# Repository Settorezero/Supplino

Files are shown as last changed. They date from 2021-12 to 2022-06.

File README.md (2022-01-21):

# Supplino

Supplino is a _Quick & Dirty_ PSU (_Power Supply Unit_) made with some widely available breakout boards, an Arduino Nano (or an Arduino Nano Every) and a graphical LCD.

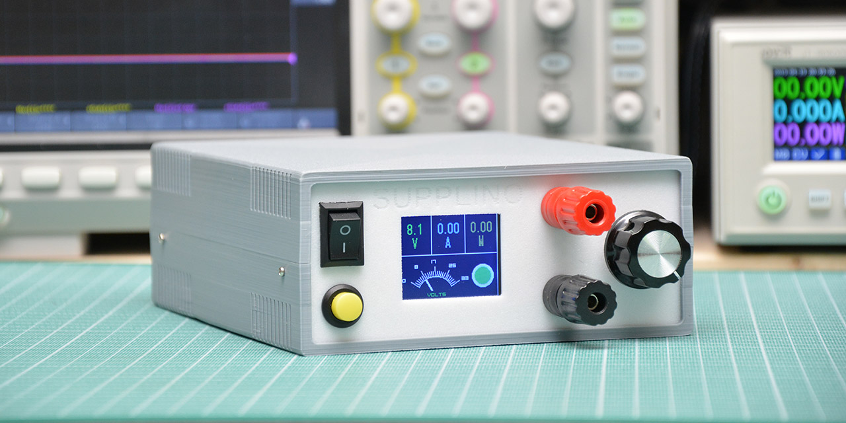
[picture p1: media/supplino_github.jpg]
Supplino
  

Supplino is the circuit between a costant current power source you choose and your target load. This is a flowchart showing how Supplino is made:

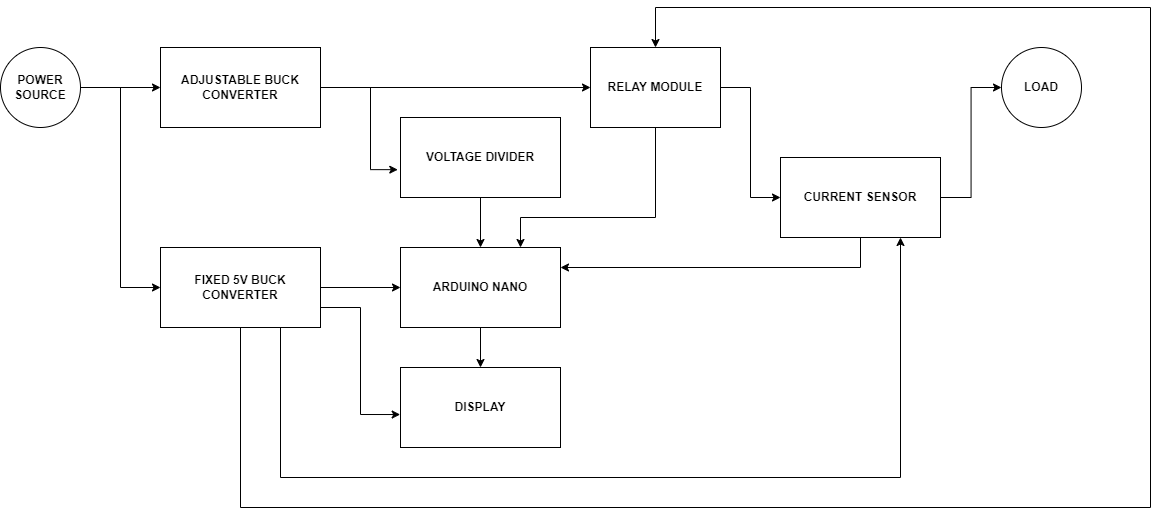
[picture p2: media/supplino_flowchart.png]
Supplino Flowchart


Power output is given by a DC/DC buck converter based on the XL4016E1 IC. Regarding the power source, we prefer feeding it through an external 20÷30V brick PSU such as the ones used for laptops or old printers: this solution is safe, but you can choose to use a larger enclosure and then include internally your own transformer+diode bridge+capacitors. Also the voltage regulation module can be changed.

Arduino does not manage the buck converter module but only measures output voltage and current (through a current sensor) and then shows those values on a display. Power value is showed too. An additional analog gauge can be configured for showing voltage, current or power value giving some retro style to the graphics.

Power output is feed through a relay, so Arduino detaches the output power sensing an external pushbutton or on alarm events (short circuit/under voltage, over-load, over-voltage).

There is a secondary DC/DC buck converter module set to 5V for powering the logics, taking input from the same input of the adjustable module.

We choosed this configuration since is cheap, simple and fully adaptable to other kinds of voltage converter designs, so the final user can choose whatever he want, also based on old-style linear voltage regulators such as the LM317 or LM338K.

We named it Supplino since we like a lot an italian snack typical of the roman cuisine, called [Supplì](https://en.wikipedia.org/wiki/Suppl%C3%AC) and because is the contraption of "Supply" and "Arduino".

### About the XH-M401 module

The XH-M401 module is based around the XL4016E1 buck converter IC. It can accept as input 4÷40V and gives an output 1.25÷36V. Manufacturer of those boards states a maximum output current of 5A that can be increased up to 8A by adding a fan, anyway we never used it for currents above 2A. This module has a switch-potentiometer for turning on/off the module and adjust the output voltage. The output current is fixed to the maximum allowable by the buck converter.

For using this module with enclosure we've designed and provided here you must remove the switch-potentiometer:

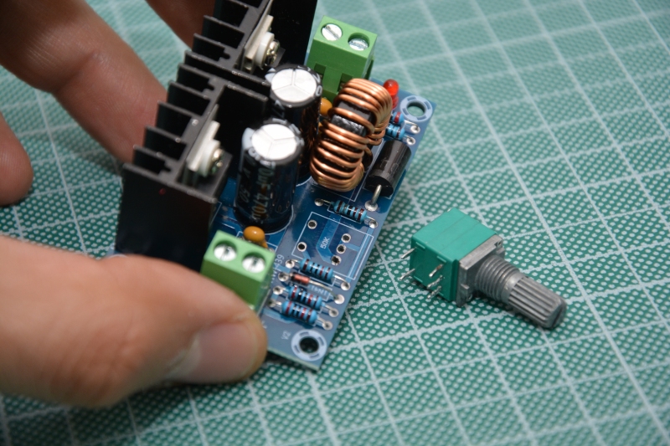
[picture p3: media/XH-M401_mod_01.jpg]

 
and then connect to the pads a 50K Multi-turn Potentiometer (better if used a JST-XH 3 pin connector) and then close with a piece of wire the switch pads (you'll turn on/off the module with a panel switch):

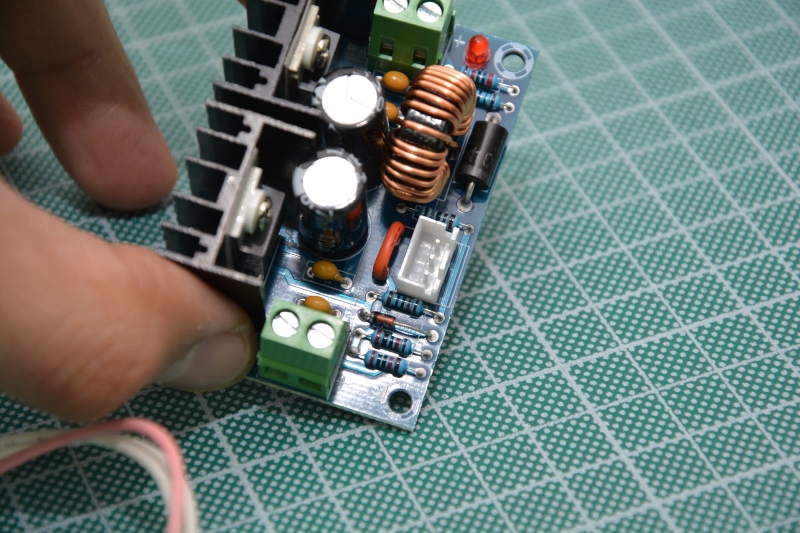
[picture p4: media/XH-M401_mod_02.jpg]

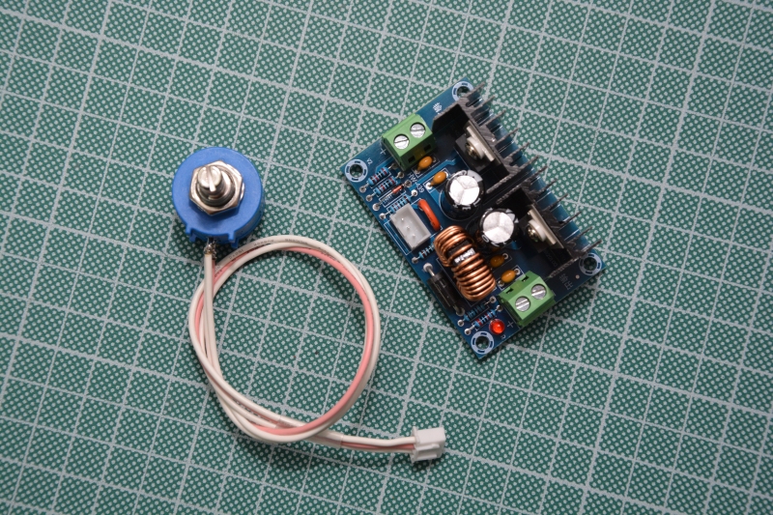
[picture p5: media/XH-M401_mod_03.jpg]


Is not adviced using a normal/single-turn potentiometer since you'll not be able to adjust the voltage in a stable manner.

- More info about the XH-M401 module: [(link)](https://www.instagram.com/p/CVqZ94OLAFN/)
- How to remove the switch-potentiometer and attach a new multi-turn one: [(link)](https://www.instagram.com/p/CWJXj0tLJGL/)

A new model of this module exists having also the possibility to regulate (_limit_) the output current [(link)](https://amzn.to/32PbnVB). This module has the same circuital design of the XH-M401 but buck converter and double diode are mounted on two separates heatsinks and it hasn't the switch-potentiometer but 2 multi-turn trimmers for adjusting voltage and current. In this case you'd remove both the trimmers, changing them with multiturn potentiometer (for voltage) and a normal single-turn linear potentiometer (for current - or a multi-turn if you want). In this case the provided enclosures will not usable anymore, so you must do your own design or choose a commercial one.

### First steps

1) Feed power in the buck converter module (LM2596s) used for giving 5V to logics. Turn the trimmer until you read 5.00V with a multimeter on the output pads. Usually a lot of turns are needed: if nothing happens after a lot of turns, try to turn in the opposite way.

2) Modify the buck converter module (XH-M401) for having the external multi-turn potentiomer and close the switch pads as explained above.

3) After you mounted all, first than attach the Arduino, check with a multimeter all the connections. Follow the schematic.

### About Arduino Nano / Every

You can use an Arduino Nano or an Arduino Nano Every. If you want to use an original Arduino board (adviced), better use the Every since is more capable (=more code) and costs less.

**Arduino Nano** : Select the board from `Tools > Board > Arduino AVR Boards > Arduino Nano`.
Most of non-original Arduino Nano boards requires to be configured in Arduino IDE for using the old bootloader: `Tools > Processor > ATMega328P (old bootloader)`. 

**Arduino Nano Every**: Pinout of this board is compatible 1:1 with the Nano. Select the board from `Tools > Board > Arduino megaAVR Boards > Arduino Nano Every`. For using the code unchanged select `Tools > Registers Emulation > ATMEGA328`

### Enclosure

We've designed 2 different enclosures. They're both based on the [Ultimate Box Maker](https://www.thingiverse.com/thing:1264391) by "HeartMan" on Thingiverse and are made for modules we used and listed in the "required parts" paragraph.

You can download and customize the original enclosure project from Thingiverse if you want to make your own enclosure. See [/cad/stl folder](/cad/stl) for further informations on provided STLs to be 3Dprinted.  
  
In the part list are listed 2 protoboards to be used with the Enclosure Variant1 : The 50x70 one will house connectors, LM2596 buck converter, Arduino Nano and components. The 30x70 protoboard will house the level shifter and the display.  

### Schematic

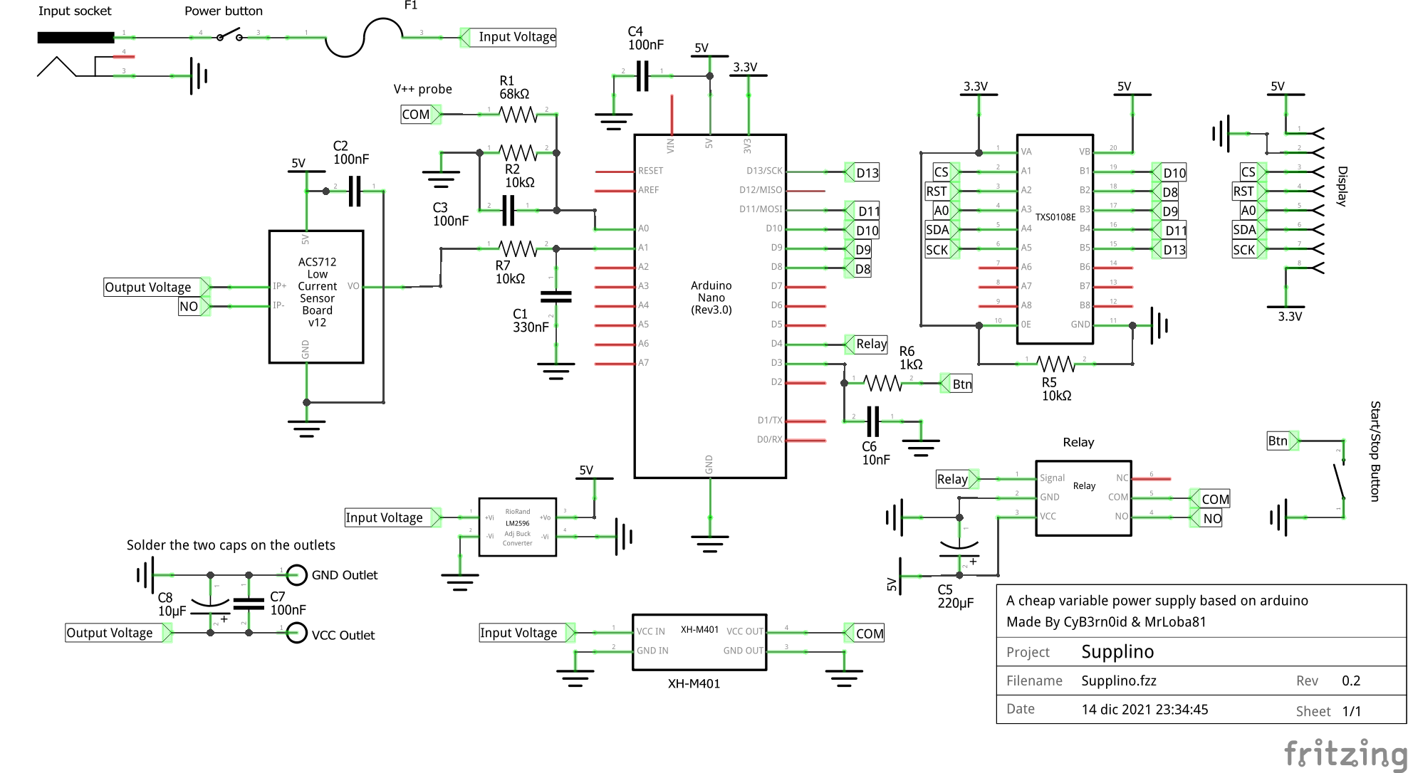
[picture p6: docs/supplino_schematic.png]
schematic


Please note : the resistor/capacitor on the pushbutton is strongly required for filtering noise that leads relay to attach/detach without reason.
 
### Required Parts

Following links contains an affiliation code for Italian Users so we can earn money if you buy something from following links (only valid for Amazon.it)

Internal parts:
- [1.8" 128x160 Display (ST7735)](https://amzn.to/3pBmids)
- [8bit Level Shifter - TXS0108E](https://amzn.to/3DoPg4V)
- [Current sensor 20A - ACS712](https://amzn.to/3osdSWe)
- [DC/DC Buck converter - LM2596s](https://amzn.to/3Ghmcyd)
- [DC/DC Buck converter XH-M401 - XL4016E1](https://amzn.to/3doaTaZ)
- [Relay Module](https://amzn.to/31yBUpw)
- [**Original** Arduino Nano Every](https://amzn.to/3qYmN1V) OR [**non original** Arduino Nano (classic)](https://amzn.to/3rADJxe) 
- [Protoboard 50x70 (link to protoboard kit)](https://amzn.to/34U1kQ4)
- [Protoboard 30x70 (link to protoboard kit)](https://amzn.to/34U1kQ4)

External/Panel mount parts:
- [Pushbutton](https://amzn.to/31wBQ9O)
- [Multi-turn 50K potentiometer](https://amzn.to/3ps1PHH)(choose 50K from the list)
- [Toggle Switch](https://amzn.to/3lFTNtJ)
- [Banana socket](https://amzn.to/3opLQuq)
- [Panel Barrel jack socket 5.5x2.1](https://amzn.to/3IrCOW2)
- Optional: [Panel USB-B to MINI-USB connector](https://amzn.to/3AdUpwO)(valid only if your board has MINI instead of MICRO USB)
- Panel Fuse-Holder + fuse based on your needs

Other parts
- [M3 Brass inserts](https://amzn.to/3EF1RlO)
- Adviced: [Crimping tool kit with Dupont and JST connectors](https://amzn.to/3Ik13nW)

### Notes

The ACS712 is not the best current sensor in the world and we know, but is cheap and easily available. You'll notice some current variations also in stand-by with nothing attached: it's the price to pay. Is not a professional instrument but a diy project for non critical/hobbystic use.

### Links

- [Hackster.io](https://www.hackster.io/settorezero/supplino-diy-psu-2a47be)
- [Arduino Blog Post](https://blog.arduino.cc/2022/01/20/supplino-is-a-variable-benchtop-power-supply-that-you-can-build-yourself/)
- [Settorezero Tweet](https://twitter.com/settorezero/status/1483874052972425216?s=20)
- [Arduino Tweet](https://twitter.com/arduino/status/1484186316246036481?s=20)
- [Microchip Makes Tweet](https://twitter.com/MicrochipMakes/status/1483866954251309057?s=20)

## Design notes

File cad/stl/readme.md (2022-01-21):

### 3D-printing Enclosure

Two different enclosures are provided.

#### Variant_01 (made by @cyb3rn0id)

- Dimensions: 140x170x60 (Width x Depth x Height)
- Thickness: 2mm

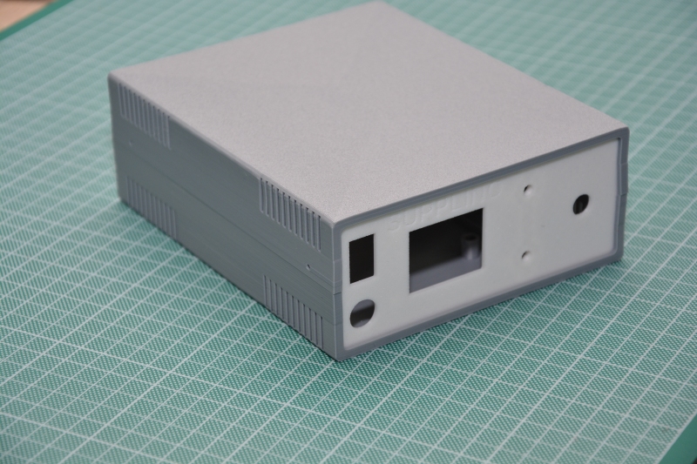
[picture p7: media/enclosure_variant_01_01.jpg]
Variant_01


There are 2 sets of 4 feets: one is for the XH-M401 module (switching regulator based on the XL4016E) and another for a 50x70 protoboard. You must insert M3 6mm brass inserts in the feets.

There are 2 slots too: one for the relay module and another for the current sensor ACS712 breakbout board. Arduino Nano and the LM2596S step-down regulator will be mounted on the protoboard. 

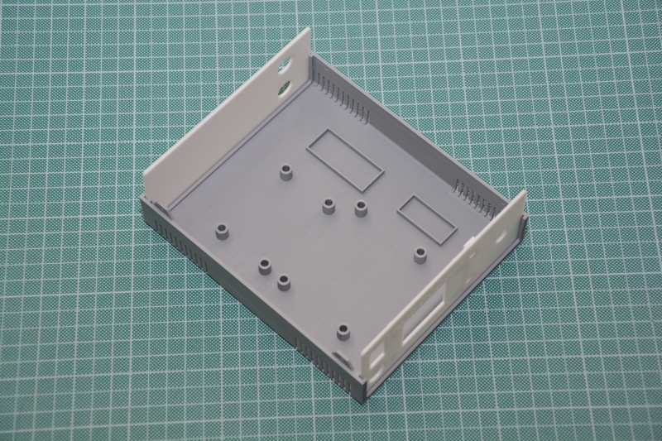
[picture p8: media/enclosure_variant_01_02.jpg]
Variant_01


Display will be attached on the front panel by screwing 4 short M3 screws without using inserts, directly in the plastic feet. You'll use a 30x70 protoboard on the back of the display for attaching the level shifter and cables

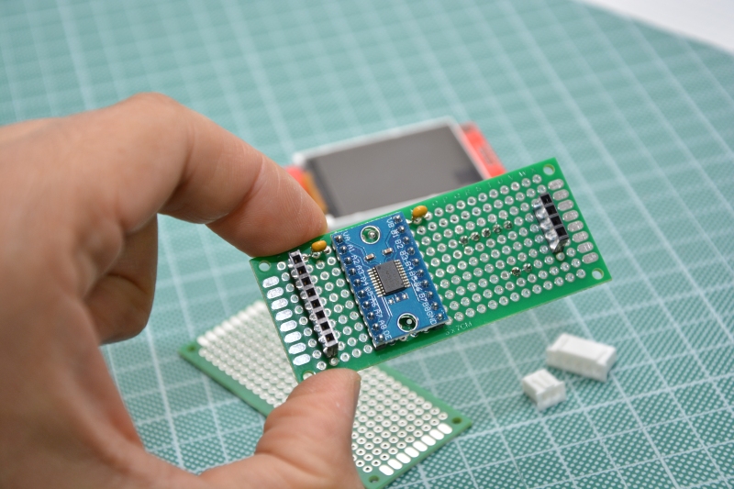
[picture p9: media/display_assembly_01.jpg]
Display Assembly


Front panel contains toggle switch, pushbutton, display, output sockets, potentiometer

For the Back panel there are 2 designs: both will contain input socket and fuse holder while the `panel_back_usb.stl` has additional holes for attaching an external USB-Type B panel connector:

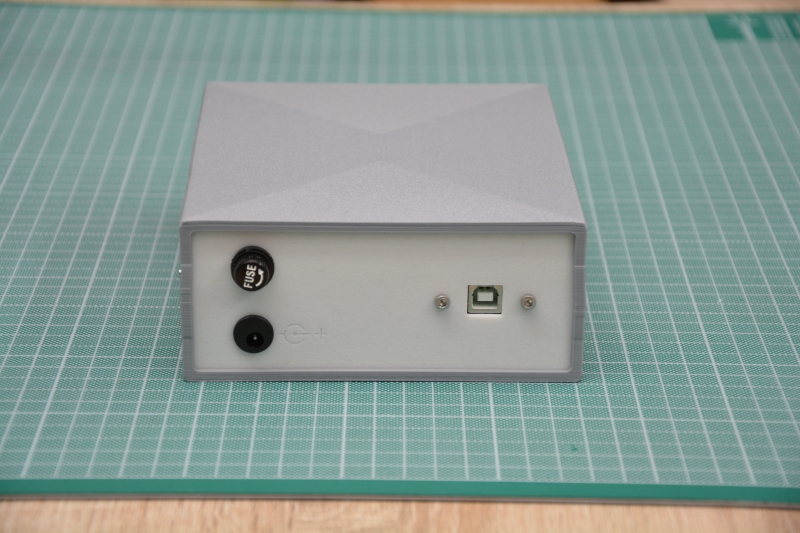
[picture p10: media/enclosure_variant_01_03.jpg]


This external USB connector will be useful to reprogramming the Arduino without open the enclosure and for eventual future revisions where the USB could be used for reading display and set certain values.

Here is showed how we attached that connector:

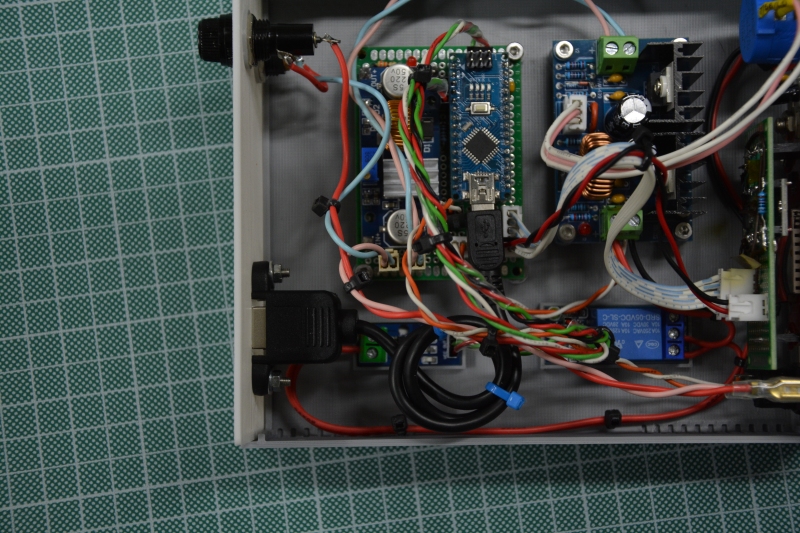
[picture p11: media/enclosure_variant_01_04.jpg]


We've used [this cable](https://amzn.to/3AdUpwO) but warning: this specific cable is good only if your Arduino Nano has the USB MINI connector (such as some third-party Arduino Nanos) so for sure is not good with the original Arduino Nano Every since uses the USB MICRO.

#### Variant_02 (made by @MrLoba81)

- Dimensions: 140x155x55 (Width x Depth x Height)
- Thickness: 2mm

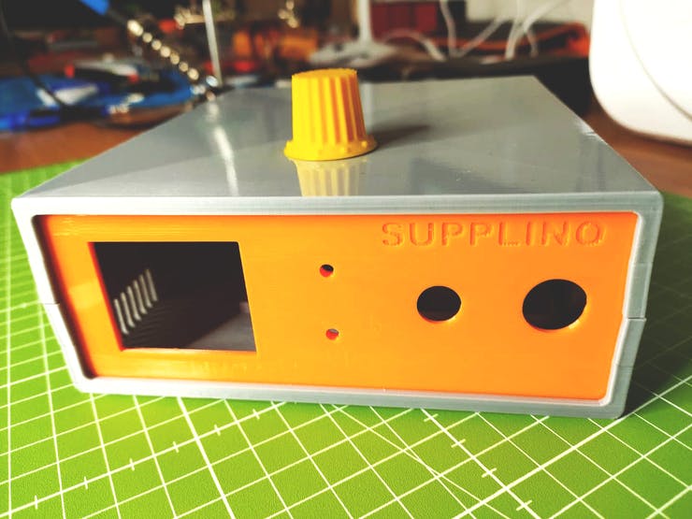
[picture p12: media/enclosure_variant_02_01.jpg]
Variant 2 enclosure


Internally There are 2 sets of 4 feets: one is for the XH-M401 module (switching regulator based on the XL4016E) and another for a 50x70 protoboard. You must insert M3 6mm brass inserts in the feets.  

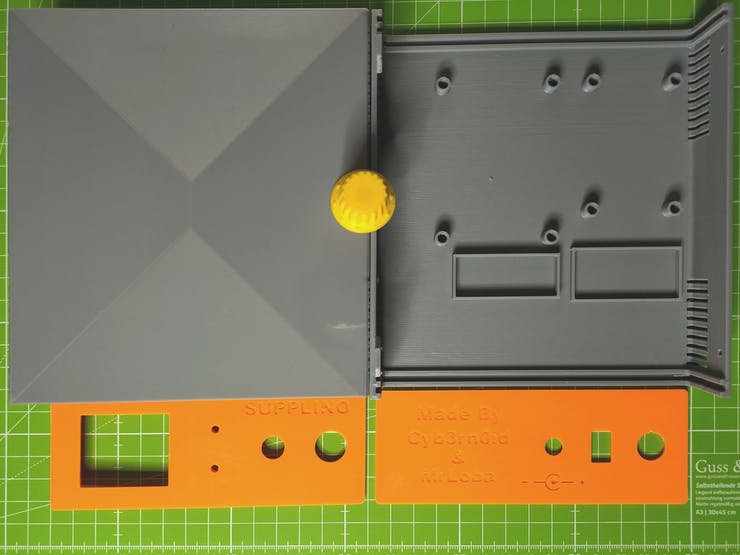
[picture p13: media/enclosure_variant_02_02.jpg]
Variant 2 enclosure


There are 2 slots too: one for the relay module and another for the  LM2596S step-down regulator. Arduino Nano and current sensor ACS712 breakbout board will be mounted on the protoboard.

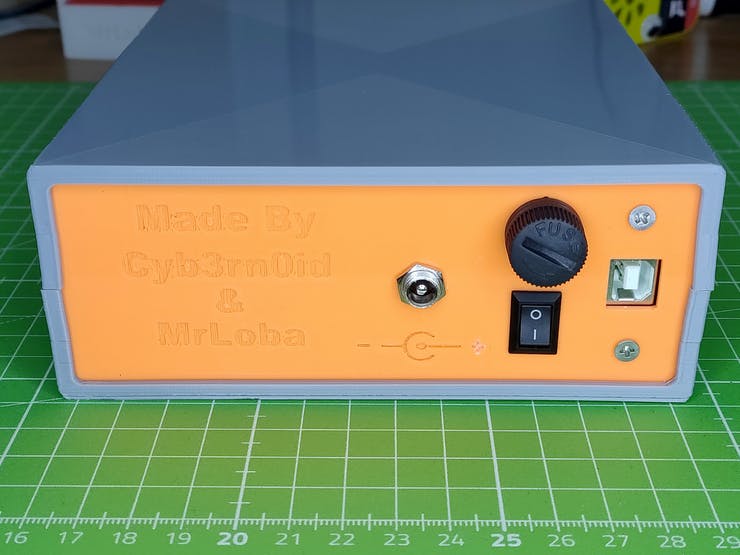
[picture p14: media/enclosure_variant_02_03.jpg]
Variant 2 enclosure


Front panel contains pushbutton, display, output sockets, potentiometer
Back panel contains toggle switch, input socket, fuse holder

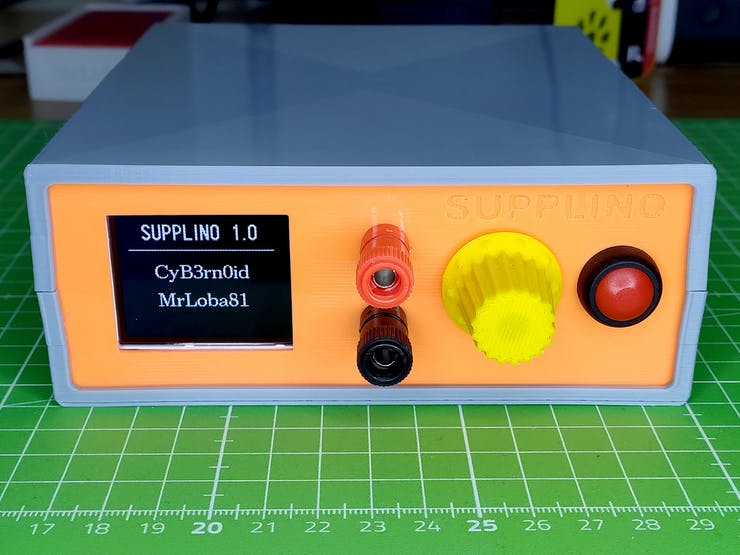
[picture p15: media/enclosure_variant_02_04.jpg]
Variant 2 enclosure


In this folder there is a knob for the potentiometer too: obviously you can use the knob also with the variant 1 enclosure.

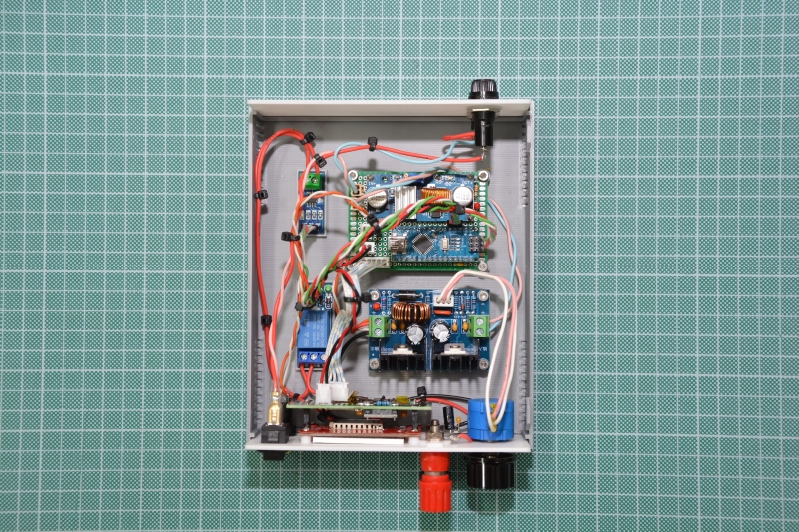
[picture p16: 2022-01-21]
media/enclosure_variant_01_05.jpg

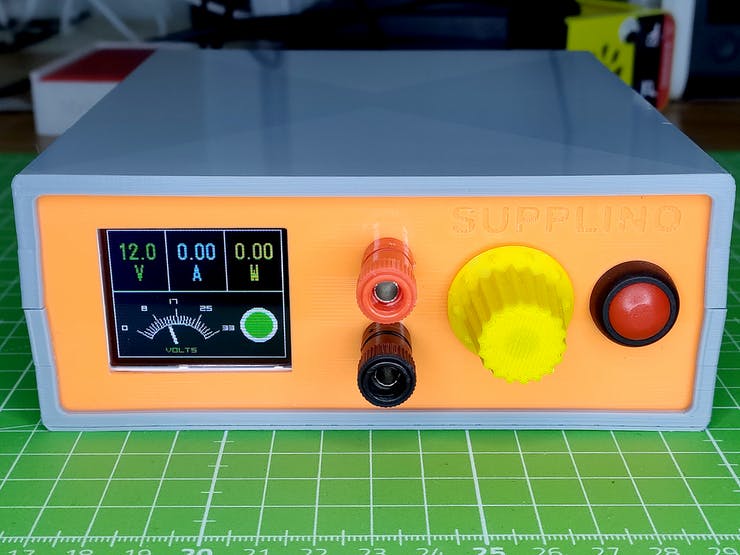
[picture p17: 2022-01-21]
media/enclosure_variant_02_05.jpg

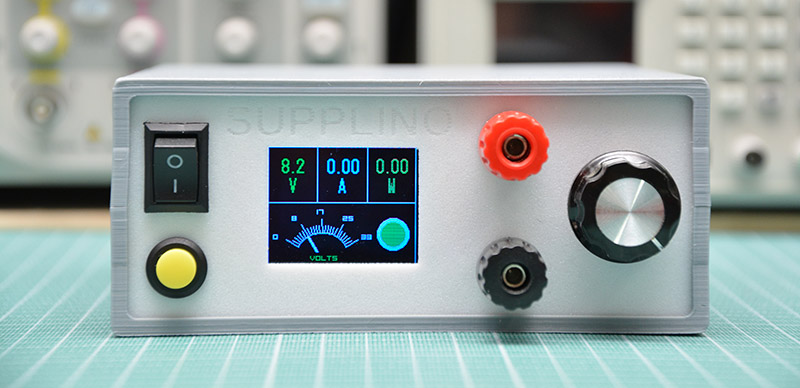
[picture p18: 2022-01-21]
media/supplino_on.jpg

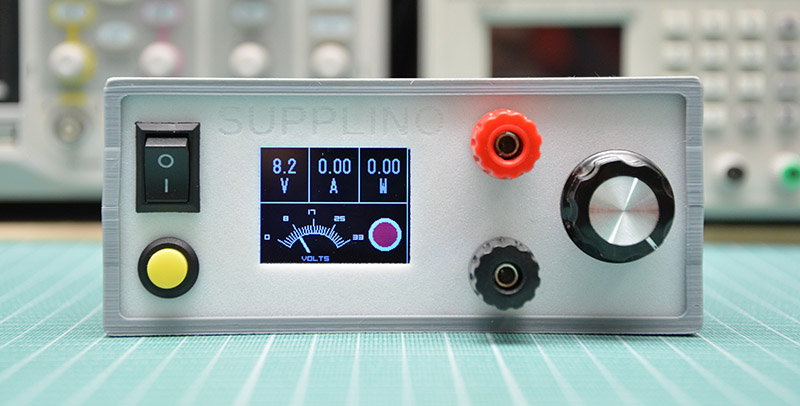
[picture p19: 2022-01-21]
media/supplino_alarm.jpg

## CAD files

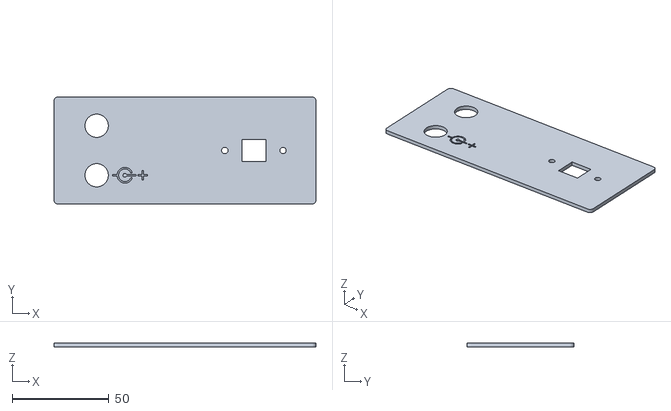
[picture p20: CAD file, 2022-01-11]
cad/stl/variant_01/panel_back_usb.stl
135.1 x 55.1 x 2.00

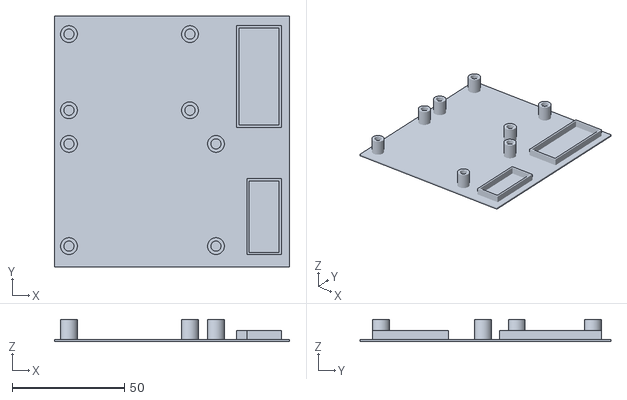
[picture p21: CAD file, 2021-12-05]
cad/stl/variant_01/tests/pcb_holders.stl
105.0 x 112.0 x 10.0

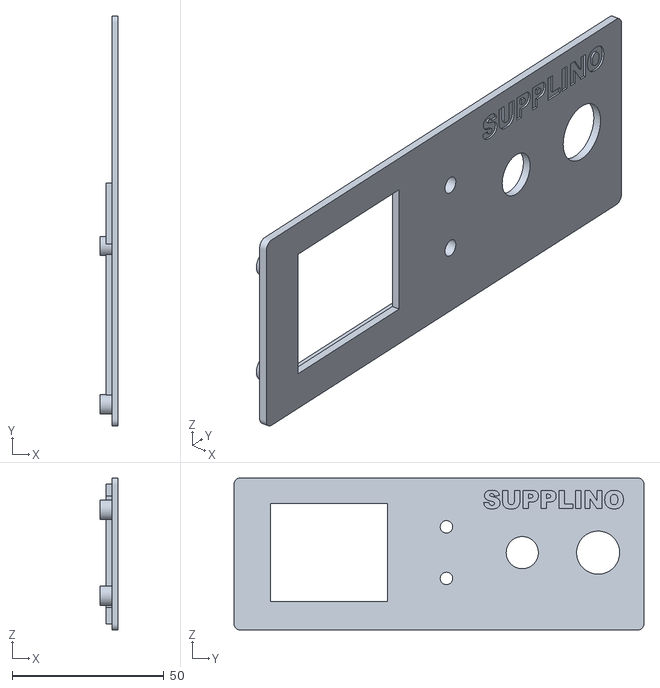
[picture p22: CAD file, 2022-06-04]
cad/stl/variant_02/FrontPanel.stl
6.00 x 135.1 x 50.1

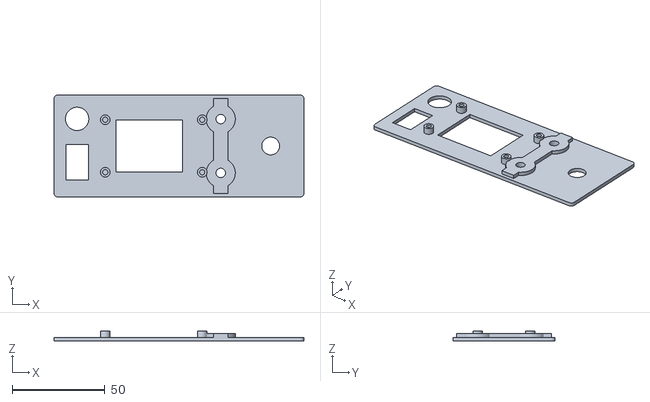
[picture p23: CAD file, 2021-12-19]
cad/stl/variant_01/panel_front.stl
135.1 x 55.1 x 5.55

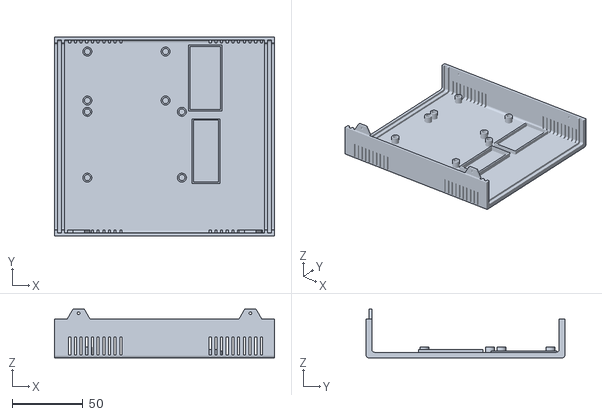
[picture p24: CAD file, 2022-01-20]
cad/stl/variant_02/Base.stl
155.0 x 140.0 x 34.4

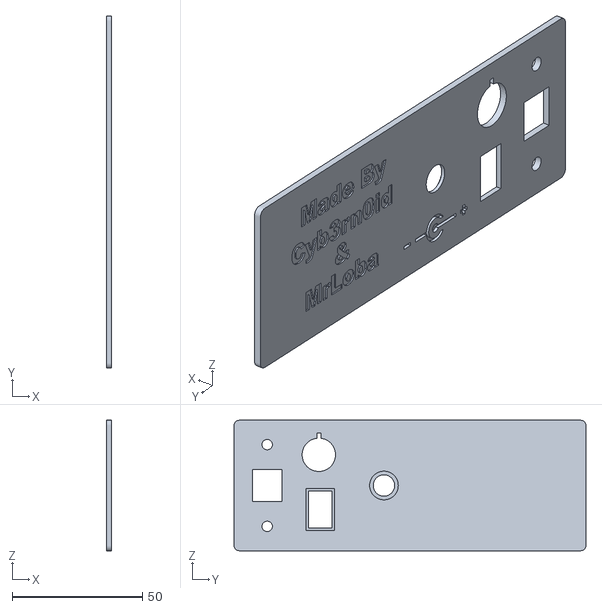
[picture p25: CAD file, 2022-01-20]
cad/stl/variant_02/BackPanel.stl
2.00 x 135.1 x 50.1

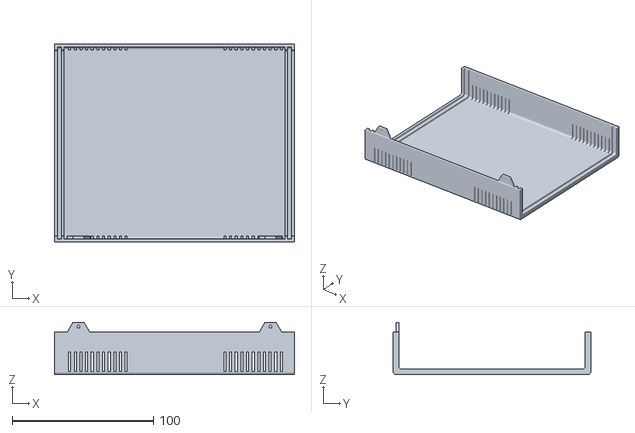
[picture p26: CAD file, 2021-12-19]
cad/stl/variant_01/enclosure_top.stl
170.0 x 140.0 x 36.9

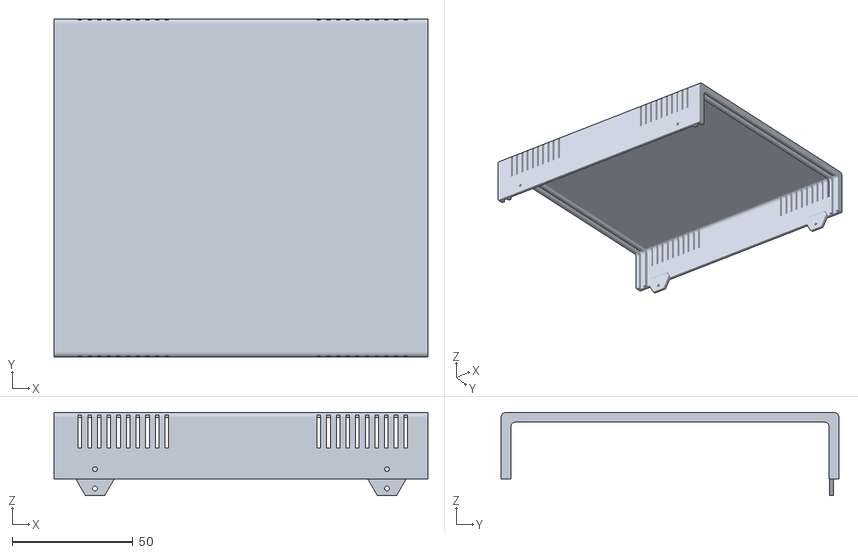
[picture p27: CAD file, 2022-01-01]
cad/stl/variant_02/Top.stl
155.0 x 140.0 x 34.4

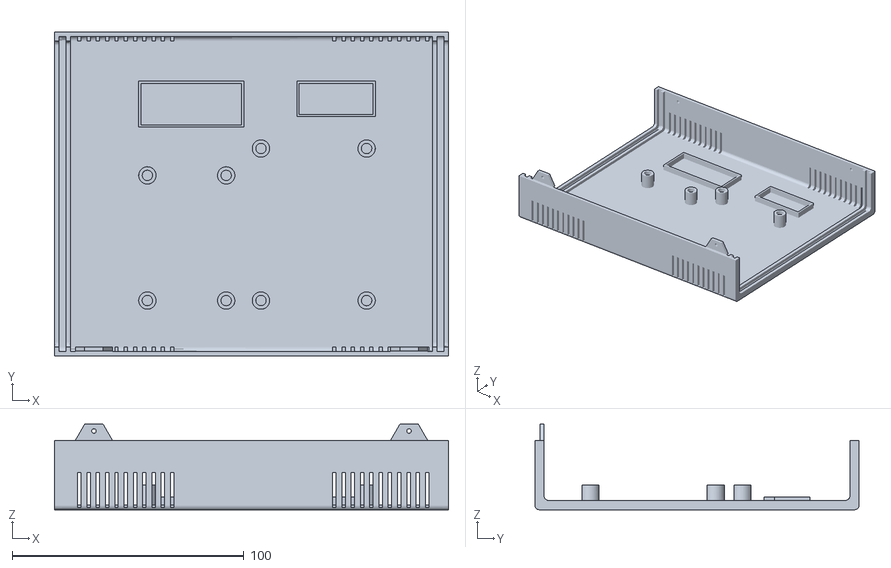
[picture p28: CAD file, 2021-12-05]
cad/stl/variant_01/ecnlosure_bottom.stl
170.0 x 140.0 x 36.9

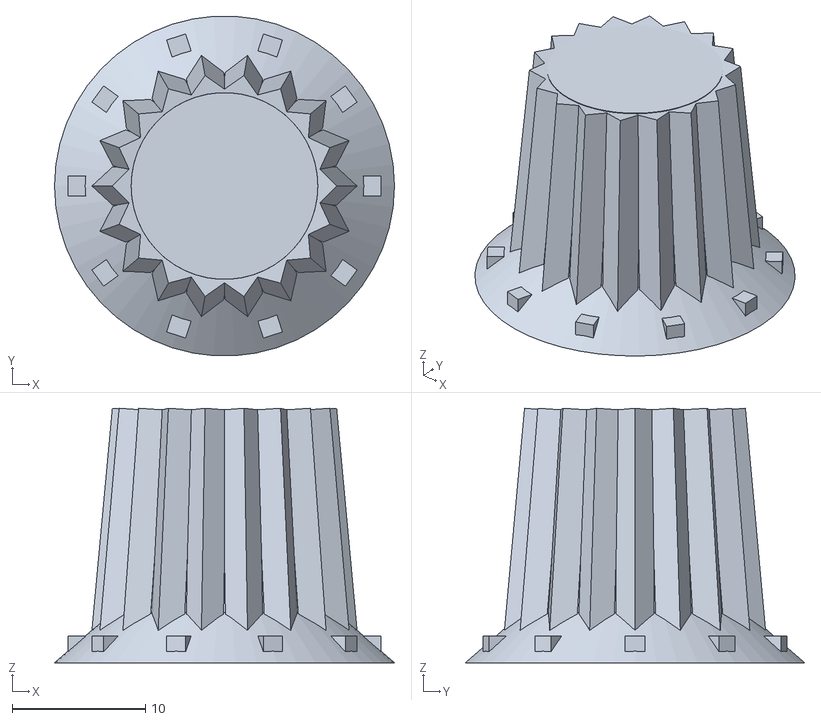
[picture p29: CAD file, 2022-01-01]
cad/stl/variant_02/Knob.stl
25.5 x 25.4 x 19.1

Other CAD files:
cad/stl/variant_01/panel_back.stl

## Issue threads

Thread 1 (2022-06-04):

variant_02/Front_Panel.stl doesn't 'fit' with associated case

tandell, 2022-06-04:
Hello,

I was getting ready to print the variant_02 case when I noticed that the Front_Panel.stl doesn't fit in the associated case.

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

Not sure if it's my slicer (Cura 5.0.0 & Cura 4.6.1), or if it got accidentally stretched during export, or something else.

This isn't blocking me or anything, I'm _probably_ going to make my own (vertical-style) case. Just thought you might want to know.

Awesome project and excellent writeup, by the way!

Ref link: https://github.com/Settorezero/Supplino/blob/main/cad/stl/variant_02/FrontPanel.stl

MrLoba81, 2022-06-04:
Hi @tandell thank you for the interest and for the issue, I have just updated the front panel STL file. Sorry for the problem. Enjoy the project ☺️

Closed 2022-06-04.

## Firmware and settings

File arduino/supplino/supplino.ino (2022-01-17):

/*
 * SUPPLINO : A Quick & Dirty PSU
 * Copyright (c) 2022 Giovanni Bernardo, Paolo Loberto.
 * 
 * https://www.github.com/settorezero/supplino
 * 
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
 * You should have received a copy of the GNU General Public License
 * along with this program. If not, see <http://www.gnu.org/licenses/>.
 */
#define SUPPLINO_VERSION "1.0"

#include <Arduino.h>
#include <SPI.h>
#include "Ucglib.h" // Ucglib by Oliver (reference: https://github.com/olikraus/ucglib/wiki/reference)
#include "gauge.hpp"
#include "acs712.hpp"

// ST7735 display to Arduino nano connections:
// CLK    : 13 (or SCL)
// SDA    : 11
// RS     :  9 (or CD or A0)
// CS     : 10
// RST    :  8 (or RES)

// display instance using software SPI (first) or hardware SPI (second)
//Ucglib_ST7735_18x128x160_SWSPI ucg(/*sclk=*/ 13, /*data=*/ 11, /*cd=*/ 9, /*cs=*/ 10, /*reset=*/ 8); // for software SPI
//Ucglib_ST7735_18x128x160_HWSPI ucg(/*cd=*/ 9, /*cs=*/ 10, /*reset=*/ 8); // for hardware SPI
Ucglib_ST7735_18x128x160_HWSPI ucg(9, 10, 8);

// Used GPIOs
// 8,9,10,11,13 not available since used by display
#define VOLTAGE_SENSE A0 // voltage divider on A0 for reading voltage output from switching regulator
#define CURRENT_SENSE A1 // analog output from ACS712 current sensor
#define RELAY          4 // relay attached on D4
#define BUTTON         3 // button attached on D3 (interrupt used)

// constants
// note: XL4016E1 IC accept from 4 to 40V at input, and outputs from 1.25 to 36V
#define RELAYON     LOW // relay module used is active low => turns on when low level is sent
#define CURRENTMAX    2 // A
#define VOLTAGEMAX   33 // V
#define VOLTAGEMIN    1 // V - used for undervoltage alarm, see "ADC_UNDERVOLTAGEALARM" below
#define POWERMAX      CURRENTMAX*VOLTAGEMAX // W
#define DIVIDERCONST  0.12821F // conversion from voltage out from divider to voltage on divider input R1=68K, R2=10K => R1/(R1+R2)
#define ADCCONV       0.00488F // 5/1024, used for conversion from ADC to voltage
#define ACSCONST      0.1F  // used 20A type that gives 100mV (0.1V) per 1 Ampere

// alarms
// Inverse formula for having ADC value from CURRENTMAX value
// currentCalibration value has to be added to this
// Current= [(ADCvalue-currentCalibration) * (5/1024)] / 0.1
// ADCvalue = [(Current * 0.1) / (5/1024)] + currentCalibration
#define ADC_CURRENTALARM int(CURRENTMAX*ACSCONST/ADCCONV)
// Inverse formula for having ADC value from VOLTAGEMAX value
#define ADC_OVERVOLTAGEALARM int(VOLTAGEMAX*DIVIDERCONST/ADCCONV)
// Inverse formula for having ADC value from VOLTAGEMIN value (used eventually for short-circuit detect)
// put since buck-converter module used outputs a minimun of 1.25V, so a voltage less than
// 1V can be interpreted as short circuit. If you don't need that, put "VOLTAGEMIN" to 0
#define ADC_UNDERVOLTAGEALARM int(VOLTAGEMIN*DIVIDERCONST/ADCCONV)

// colors used for Voltage, Current and Power (background=1/foreground=0, R, G, B)
#define SET_V_COLOR ucg.setColor(0, 0, 250, 0)
#define SET_I_COLOR ucg.setColor(0, 0, 150, 255)
#define SET_W_COLOR ucg.setColor(0, 204, 204, 0)

// voltage adjustment
//#define VOLT_ADJ(V)  V // for no correction
#define VOLT_ADJ(V) V+0.2F // your own formula

// current adjustment
//#define CURR_ADJ(I) I // for no correction
#define CURR_ADJ(I) I-0.015F // your own formula

Gauge gauge(&ucg); // analog gauge instance
// constants used for the analog gauge
#define G_X 59
#define G_Y 123
#define G_ARC 120
#define G_RADIUS 30

enum gaugeType {
  V,
  I,
  W
};

enum alarmType {
  no_alarm,
  over_load,
  over_voltage,
  under_voltage,
};

alarmType alarm = no_alarm;

gaugeType showedGauge = V;
volatile bool outputEnabled = false; // output relay detached
volatile bool skipInterrupt = true;

ACS712 acs712(VOLTAGE_SENSE, CURRENT_SENSE, ADCCONV, ACSCONST);
//------------------------------------------------------------------------------------------------------------

// toggle relay allowing power output
void outputEnable(void)
{
  outputEnabled = true;
  digitalWrite(RELAY, RELAYON);
}

// toggle relay disabling power output
void outputDisable(void)
{
  outputEnabled = false;
  digitalWrite(RELAY, !RELAYON);
}

// Interrupt Service Routine at button state change
// from low to high (button release)
void ISR_buttonPress(void)
{
  static long lastPress = 0;
  
  if (skipInterrupt) // routine in the main on the long press said to skip this interrupt
  {
    skipInterrupt = false;
    interrupts();
    return;
  }

  noInterrupts(); // disable interrupts
  
  if ((millis() - lastPress) < 200)
  {
    // exit if <200mS press
    lastPress = millis();
    interrupts(); // re-enable interrupts
    return;
  }
  // in an alarm status, first press reset the alarm
  // second press will re-enable the power output
  if (alarm != no_alarm)
  {
    alarm = no_alarm; // reset alarm status...
    lastPress = millis();
    interrupts();
    return; // ... but remain with relay off
  }
  outputEnabled ? outputDisable() : outputEnable(); // toggle
  //while (!digitalRead(BUTTON)); // eventually stay stuck until button released
  lastPress = millis();
  interrupts(); // re-enable interrupts
}

// set alarm disabling the output
void setAlarm(alarmType alm)
{
  alarm = alm; // alarm is global
  outputDisable();
  outputIcon();
}

void setup(void)
  {
  pinMode(RELAY, OUTPUT);
  outputDisable();
  pinMode(BUTTON, INPUT_PULLUP);
  Serial.begin(57600);
  delay(200);
  Serial.print("Supplino V.");
  Serial.println(SUPPLINO_VERSION);
  Serial.println("By Cyb3rn0id and MrLoba81");
  
  ucg.begin(UCG_FONT_MODE_TRANSPARENT);
  ucg.clearScreen();
  ucg.setRotate270(); // 90=display horizontal (landscape) with data header on the left

  // paint screen in black
  ucg.setColor(0, 0, 0, 0);
  ucg.drawBox(0, 0, ucg.getWidth(), ucg.getHeight());

  // set font
  ucg.setColor(0, 255, 255, 255); // foreground color
  ucg.setColor(1, 0, 0, 0); // background color
  ucg.setFontMode(UCG_FONT_MODE_SOLID); // solid: background will painted
  ucg.setFont(ucg_font_logisoso16_hr); // font (https://github.com/olikraus/ucglib/wiki/fontsize)
  ucg.setPrintDir(0);
  ucg.drawHLine(10, 35, 140);
  ucg.setPrintPos(23, 25);
  ucg.print("SUPPLINO ");
  ucg.print(SUPPLINO_VERSION);
  ucg.setFont(ucg_font_ncenR14_hr);
  ucg.setPrintPos(34, 65);
  ucg.print("CyB3rn0id");
  ucg.setPrintPos(35, 95);
  ucg.print("MrLoba81");

  acs712.setVoltageAdjustCB([](float &v_val)
  {
    // voltage from divider output to voltage on divider input
    // and user adjustment
    return VOLT_ADJ(v_val / DIVIDERCONST);
  });

  acs712.setCurrentAdjustCB([](float &i_val)
  {
    // user adjustment
    return CURR_ADJ(i_val);
  });

  acs712.setVoltageCheckCB([](uint16_t &v_val)
  {
    // quickly check a short-circuit
    if (v_val < ADC_UNDERVOLTAGEALARM)
    {
      setAlarm(under_voltage);
      return false;
    }
    // quickly check an over-voltage. Dunno if useful or not, maybe a broken switching module can output voltage unregulated?
    if (v_val > ADC_OVERVOLTAGEALARM)
    {
      setAlarm(over_voltage);
      return false;
    }
    return true;
  });

  acs712.setCurrentCheckCB([](uint16_t &i_val)
  {
    if (i_val > acs712.getCurrentCalibration() + ADC_CURRENTALARM)
    {
      setAlarm(over_load);
      return false;
    }

    return true;
  });

  // calibrate zero current value
  outputDisable(); // disable output in calibration mode
  Serial.println("Zeroing current sensor");
  acs712.computeReadings(true);

  delay(1500);

  // paint screen in black
  ucg.setColor(0, 0, 0, 0);
  ucg.drawBox(0, 0, ucg.getWidth(), ucg.getHeight());

  // draw gauge scale
  drawGaugeScale();

  // draw decorations
  ucg.setColor(0, 255, 255, 255); // foreground color
  ucg.setColor(1, 0, 0, 0); // background color
  // frame & separation lines
  ucg.drawFrame(0, 0, 160, 128);
  ucg.drawHLine(0, 60, 160);
  ucg.drawVLine(53, 0, 60);
  ucg.drawVLine(107, 0, 60);
  // led border
  ucg.drawDisc(135, 94, 17, UCG_DRAW_ALL);

  // enable interrupt on button release
  attachInterrupt(digitalPinToInterrupt(BUTTON), ISR_buttonPress, RISING);
  delay(100);
  Serial.println("Setup done");
}

void loop(void)
{
  static unsigned long lastCheck = millis();
  if (digitalRead(BUTTON) == LOW) // interrupt not happened: ISR will fire after button will be released
  {
    if (millis() - lastCheck >= 1000) { // button pressed for more than a second
      skipInterrupt = true;
      showedGauge = showedGauge == V ? I : (showedGauge == I ? W : V);
      drawGaugeScale();
      updateGauge();
      lastCheck = millis();
    }
  } else { // button not pressed
    lastCheck = millis();
  }
  // re-set font since gauge uses another kind of font
  ucg.setFontMode(UCG_FONT_MODE_SOLID); // solid: background will painted
  ucg.setFont(ucg_font_logisoso16_hr); // font (https://github.com/olikraus/ucglib/wiki/fontsize)
  ucg.setPrintDir(0);

  // update values
  acs712.computeReadings(false);
  printValues();
  updateGauge();
  outputIcon();
}

// draw Analog gauge scale
void drawGaugeScale(void)
{
  ucg.setColor(1, 0, 0, 0);
  ucg.setColor(0, 0, 0, 0);
  ucg.drawBox(1, 61, 115, 62);
  switch (showedGauge)
  {
    case I:
      gauge.drawGauge(G_X, G_Y, G_ARC, G_RADIUS, 5, 15, 0, CURRENTMAX, 0, CURRENTMAX - 1, CURRENTMAX - 1);
      gauge.drawPointer(G_X, G_Y, G_ARC, G_RADIUS, -1, 0, CURRENTMAX);
      break;
    case W:
      gauge.drawGauge(G_X, G_Y, G_ARC, G_RADIUS, 5, 15, 0, POWERMAX, 0, POWERMAX - 1, POWERMAX - 1);
      gauge.drawPointer(G_X, G_Y, G_ARC, G_RADIUS, -1, 0, POWERMAX);
      break;
    default:
      gauge.drawGauge(G_X, G_Y, G_ARC, G_RADIUS, 5, 15, 0, VOLTAGEMAX, 0, 0, 0);
      gauge.drawPointer(G_X, G_Y, G_ARC, G_RADIUS, -1, 0, VOLTAGEMAX);
      break;
  }
}

// update analog gauge pointer
void updateGauge(void)
{
  switch (showedGauge)
  {
    case I:
      gauge.drawPointer(G_X, G_Y, G_ARC, G_RADIUS, acs712.getCurrent(), 0, CURRENTMAX);
      ucg.setFontMode(UCG_FONT_MODE_SOLID);
      ucg.setFont(ucg_font_orgv01_hf);
      ucg.setPrintPos(G_X - 16, G_Y);
      outputEnabled ? (SET_I_COLOR) : ucg.setColor(0, 90, 90, 90);
      ucg.print("AMPERE");
      break;

    case W:
      gauge.drawPointer(G_X, G_Y, G_ARC, G_RADIUS, acs712.getPower(), 0, POWERMAX);
      ucg.setFontMode(UCG_FONT_MODE_SOLID);
      ucg.setFont(ucg_font_orgv01_hf);
      ucg.setPrintPos(G_X - 13, G_Y);
      outputEnabled ? (SET_W_COLOR) : ucg.setColor(0, 90, 90, 90);
      ucg.print("WATTS");
      break;

    default:
      gauge.drawPointer(G_X, G_Y, G_ARC, G_RADIUS, acs712.getVoltage(), 0, VOLTAGEMAX);
      ucg.setFontMode(UCG_FONT_MODE_SOLID);
      ucg.setFont(ucg_font_orgv01_hf);
      ucg.setPrintPos(G_X - 13, G_Y);
      outputEnabled ? (SET_V_COLOR) : ucg.setColor(0, 90, 90, 90);
      ucg.print("VOLTS");
      break;
  }
}

// print digital values
void printValues()
{
  static float preV = 0;
  static float preI = 0;
  static float preW = 0;

  // draw a black box passing from a value >10 to a value<10
  ucg.setColor(1, 0, 0, 0);
  ucg.setColor(0, 0, 0, 0);
  if (preV >= 10.0 && acs712.getVoltage() < 10.0) ucg.drawBox(1, 12, 51, 18);
  outputEnabled ? SET_V_COLOR : ucg.setColor(0, 90, 90, 90); // default color is gray
  acs712.getVoltage() < 10.0 ? ucg.setPrintPos(14, 29) : ucg.setPrintPos(8, 29);
  ucg.print(acs712.getVoltage(), 1);
  ucg.setPrintPos(22, 50);
  ucg.print("V");

  // draw a black box passing from a value >10 to a value<10
  ucg.setColor(1, 0, 0, 0);
  ucg.setColor(0, 0, 0, 0);
  if (preI >= 10.0 && acs712.getCurrent() < 10.0) ucg.drawBox(54, 12, 52, 18);
  outputEnabled ? SET_I_COLOR : ucg.setColor(0, 90, 90, 90); // default color is gray
  acs712.getCurrent() < 10.0 ? ucg.setPrintPos(63, 29) : ucg.setPrintPos(60, 29);
  ucg.print(acs712.getCurrent(), acs712.getCurrent() >= 10.0 ? 1 : 2);
  if (acs712.getCurrent() >= 10.0) ucg.print(" ");
  ucg.setPrintPos(75, 50);
  ucg.print("A");

  // draw a black box passing from a value >10/>20 to a value<10/<20
  // not tested with values over 99.9
  ucg.setColor(1, 0, 0, 0);
  ucg.setColor(0, 0, 0, 0);
  if ((preW >= 10.0 && acs712.getPower() < 10.0) || (preW >= 20.0 && acs712.getPower() < 20.0) || (preW < 10.0 && acs712.getPower() >= 10.0))
  {
    ucg.drawBox(108, 12, 51, 18);
  }
  outputEnabled ? SET_W_COLOR : ucg.setColor(0, 90, 90, 90); // default color is gray
  acs712.getPower() < 10.0 ? ucg.setPrintPos(116, 29) : (acs712.getPower() >= 20.0 ? ucg.setPrintPos(115, 29) : ucg.setPrintPos(113, 29));
  ucg.print(acs712.getPower(), acs712.getPower() <= 10.0 ? 2 : (acs712.getPower() < 100.0 ? 1 : 0));
  ucg.setPrintPos(128, 50);
  ucg.print("W");

  preV = acs712.getVoltage();
  preI = acs712.getCurrent();
  preW = acs712.getPower();
}

// draw round icon indicating power output status
void outputIcon(void)
{
  if (outputEnabled)
  {
    ucg.setColor(0, 0, 255, 0); // green
  }
  else
  {
    if (alarm == no_alarm)
    {
      ucg.setColor(0, 90, 90, 90); // gray
    }
    else
    {
      ucg.setColor(0, 255, 0, 0); // red
    }
  }
  ucg.drawDisc(135, 94, 13, UCG_DRAW_ALL);
}

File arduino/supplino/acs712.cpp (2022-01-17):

/*
 * ACS712 and voltage divider custom library
 * Copyright (c) 2022 Paolo Loberto
 * 
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
 * You should have received a copy of the GNU General Public License
 * along with this program. If not, see <http://www.gnu.org/licenses/>.
 */
#include "acs712.hpp"

ACS712::ACS712(uint8_t vPin, uint8_t iPin, float adcConv, float voltsAmpere) : voltage(0), current(0), power(0), currentDecimals(1), currentCalibration(512), vPin(vPin), iPin(iPin), adcConv(adcConv), voltsAmpere(voltsAmpere)
{}

float ACS712::getVoltage()
{
  return this->voltage;
}

float ACS712::getCurrent()
{
  return this->current;
}

float ACS712::getPower()
{
  return this->power;
}

void ACS712::setVoltageAdjustCB(ADJUST_VOLTAGE)
{
  this->adjustVotlage = adjustVotlage;
}

void ACS712::setCurrentAdjustCB(ADJUST_CURRENT)
{
  this->adjustCurrent = adjustCurrent;
}

void ACS712::setCurrentCheckCB(CHECK_CURRENT)
{
  this->checkCurrent = checkCurrent;
}

void ACS712::setVoltageCheckCB(CHECK_VOLTAGE)
{
  this->checkVoltage = checkVoltage;
}

float ACS712::getCurrentCalibration()
{
  return this->currentCalibration;
}

// compute readings fuction
// calibration=true => don't read voltage and store zero current value (calibration)
// calibration=false =>  read voltage too and use current calibration value to adjust the current value
bool ACS712::computeReadings(bool calibration)
{
  float i_val = 0.0; // current value (Ampere)
  float v_val = 0.0 ; // voltage value (Volt)
  uint16_t anValue = 0; // ADC raw readings from ACS sensor and from voltage divider
  uint8_t i = 0; // generic counter

  // read current value
  for (i = 0; i < IREADINGS; i++)
  {
    anValue = analogRead(this->iPin);
    // quickly detect an overload. This occurs also in case of a short-circuit
    if (this->checkCurrent && !this->checkCurrent(anValue)) {
      return false;
    }
    i_val += anValue;
  } // end current reading cycle
  i_val /= IREADINGS; // average

  // calibration mode=>store average value from ADC as ZERO (OFFSET) current
  if (calibration)
  {
    this->currentCalibration = i_val;
    return true; // exit from function
  }
  else // is not calibration
  {
    // normally you'll subtract an 2.5V offset, but better read the standby value (previous functions)
    // and then subtract that value (anyway in good conditions would be around 2.5V => around 512)
    i_val = i_val - this->currentCalibration;
    // turn (eventually) negative value in positive since we're working only on DC
    // and can happen we wired the current sensor in inverse way
    if (i_val < 0) i_val *= -1;
    // compute current value in Ampere
    i_val *= this->adcConv; // ADC to voltage in V
    i_val /= this->voltsAmpere; // Voltage to Ampere using the sensor constant

    if (this->adjustCurrent) {
      i_val = this->adjustCurrent(i_val);
    }
    if (i_val < 0) i_val = 0; // if user adjustment makes value less than zero, turn to zero
    this->current = i_val; // store value for gauges
  }

  // read voltage (and compute power) too if not in calibration mode
  if (!calibration)
  {
    for (i = 0; i < VREADINGS; i++)
    {
      anValue = analogRead(this->vPin);
      // quickly check a short-circuit or an over-voltage
      if (this->checkVoltage && !this->checkVoltage(anValue)) {
        return false;
      }
      v_val += anValue;
    } // end voltage reading cycle
    v_val /= VREADINGS; // average
    v_val *= this->adcConv;// ADC to voltage in V

    if (this->adjustVotlage) {
      v_val = this->adjustVotlage(v_val);
    }

    this->voltage = v_val;
    if (this->current<.01)
      {this->power=0;}
    else
      {this->power = this->voltage * this->current;} // active power

    return true;
  } // not current calibration => read voltage too
} // \computeReadings

void ACS712::calibrate()
{
  this->computeReadings(true);
}

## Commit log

2021-12-05 added STLS for enclosure variant01
    [ecnlosure_bottom.stl, enclosure_top.stl, panel_front.stl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]
2021-12-15 Potentiometer custom knob
    [CustomKnob.stl]
2021-12-19 updated enclosure
    [enclosure_top.stl, panel_back.stl, panel_front.stl]
2021-12-19 working button and short circuit alarm
    [supplino.ino]
2021-12-26 Updated display frame
    [FrontPanel.stl, FrontPanelWithText.stl]
2021-12-29 code refactoring, new functions
    parametrized the whole things
    gauges on separate files
    alarms gets quick on event
    current value more stable
    parametrized alarms so can be eventually shown on display
2021-12-30 macro for adjustments
    - macros for current and voltage adjustements
    - version
    - splash screen
2021-12-31 added schematic and project description
2022-01-01 more parametrization
    - parametrized showed gauge to be used from serial commands in future
    - parametrized voltagemin value
    - some constant name changed
2022-01-01 corrected some bugs
    - corrected digital voltage update (sometimes characters remains).
    - removed a decimal from the digital voltage gauge: not useful
    - corrected bug: analog gauge measure unit changing color at random
    - corrected behavior: now voltage updates also during an alarm
    [supplino.ino]
2022-01-01 corrected bugs. More stable.
    [supplino.ino]
2022-01-01 Box revision
    More compact revision of the box with text on front and back panel
    [BackPanel.stl, Base.stl, CustomKnob.stl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]
2022-01-02 added license - minor bugs
    - added license
    - corrected graphical bug on the showed power value
    [supplino.ino]
2022-01-04 Added feature : long press
    Added feature: cycle through showed analog gauge keeping button pressed
2022-01-11 added backpanel with usb hole
    [panel_back_usb.stl]
2022-01-17 updates
    - corrected interrupt issue
    - adjusted acs712 library for not showing a power value if current lesser than 0.01
    [acs712.cpp, supplino.ino]
2022-01-18 updated schematic
    added 50Hz low-pass filter on A1
2022-01-20 Updated the stls for Variant 2
    [BackPanel.stl, Base.stl, FrontPanel.stl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]
2022-01-21 added enclosure variant 2 pictures
2022-01-21 added flowchart
2022-01-23 More details on connections
    Added
    - input socket with power button and fuse
    - outlets
    - detailed connections of XH-M401
2022-06-04 Update FrontPanel.stl
    Updated the front panel to the latest revision
    [FrontPanel.stl]

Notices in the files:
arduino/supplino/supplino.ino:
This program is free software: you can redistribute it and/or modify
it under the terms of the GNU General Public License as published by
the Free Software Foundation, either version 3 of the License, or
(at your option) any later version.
